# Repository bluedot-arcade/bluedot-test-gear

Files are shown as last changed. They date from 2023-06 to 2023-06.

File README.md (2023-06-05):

<p align="right">
    
     
</p>
<br><br>
<p align="center">
    <h1 align="center">BlueDot Test Gear</h1>
    <p align="center">This repository contains the source code and the design files for the bluedot automated test gear.</p>
    <p align="center"><strong><a href="https://docs.bluedotarcade.com/boards/bd845-pwb">Explore the docs</a></strong></p>
    <br><br>
</p>

## Testers

- [BD845-PWB Tester](/bd845-pwb-tester/)

## License

Distributed under the MIT License. See [LICENSE.txt] for more information.

<p align="right">(<a href="#readme-top">back to top</a>)</p>

[LICENSE.txt]: /LICENSE.txt
[PlatformIO Core Docs]: https://docs.platformio.org/en/latest/core/index.html
[PlatformIO Docs]: https://docs.platformio.org/

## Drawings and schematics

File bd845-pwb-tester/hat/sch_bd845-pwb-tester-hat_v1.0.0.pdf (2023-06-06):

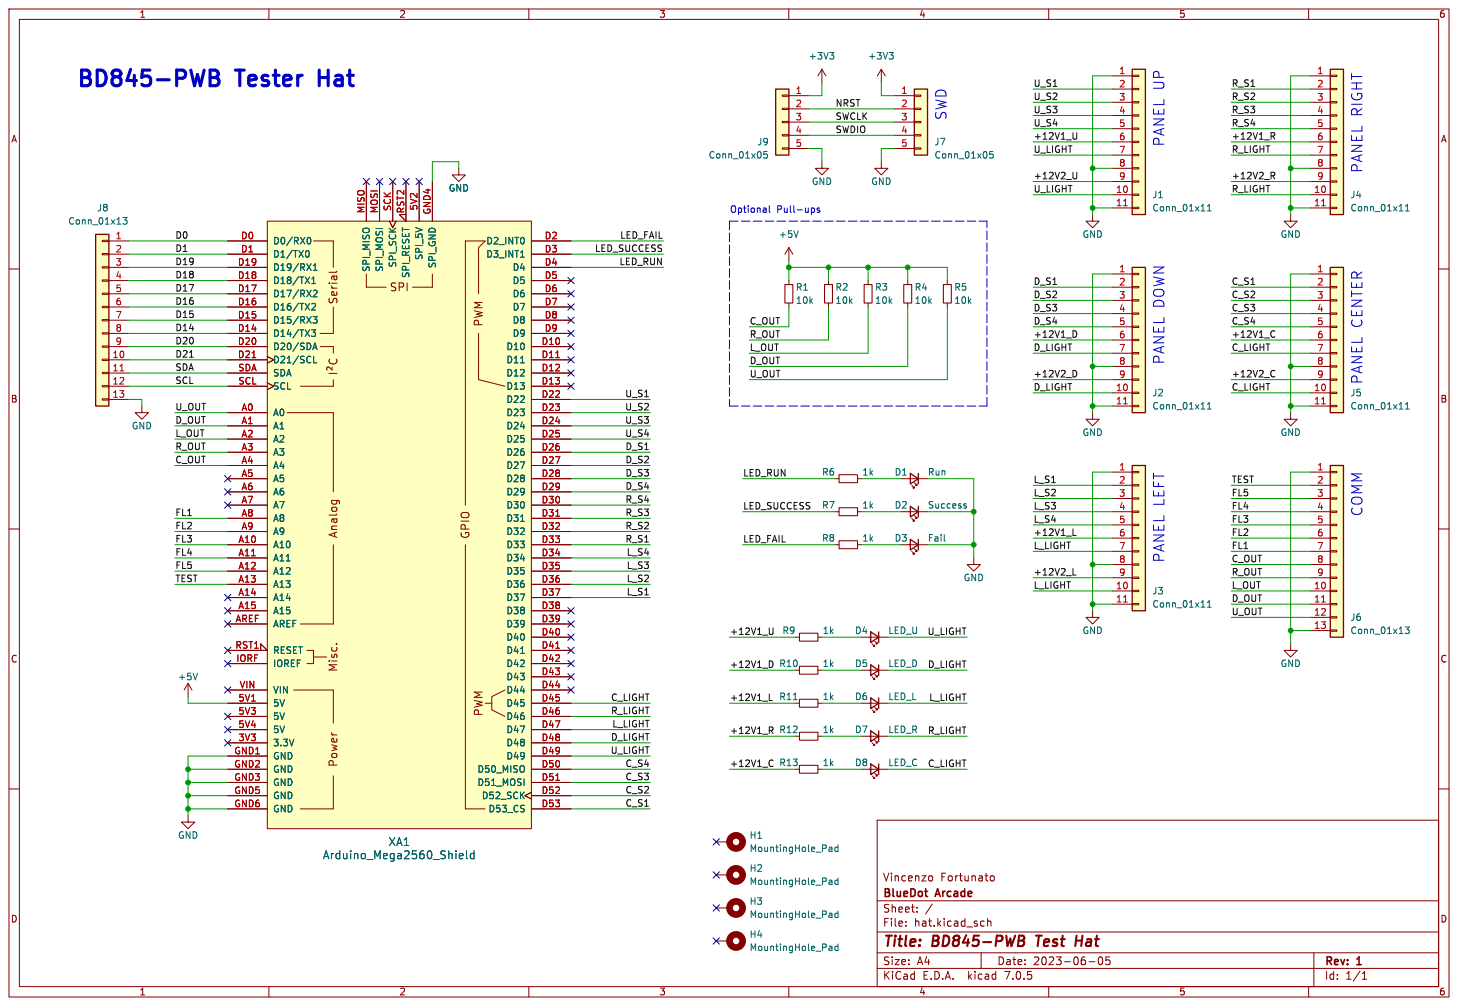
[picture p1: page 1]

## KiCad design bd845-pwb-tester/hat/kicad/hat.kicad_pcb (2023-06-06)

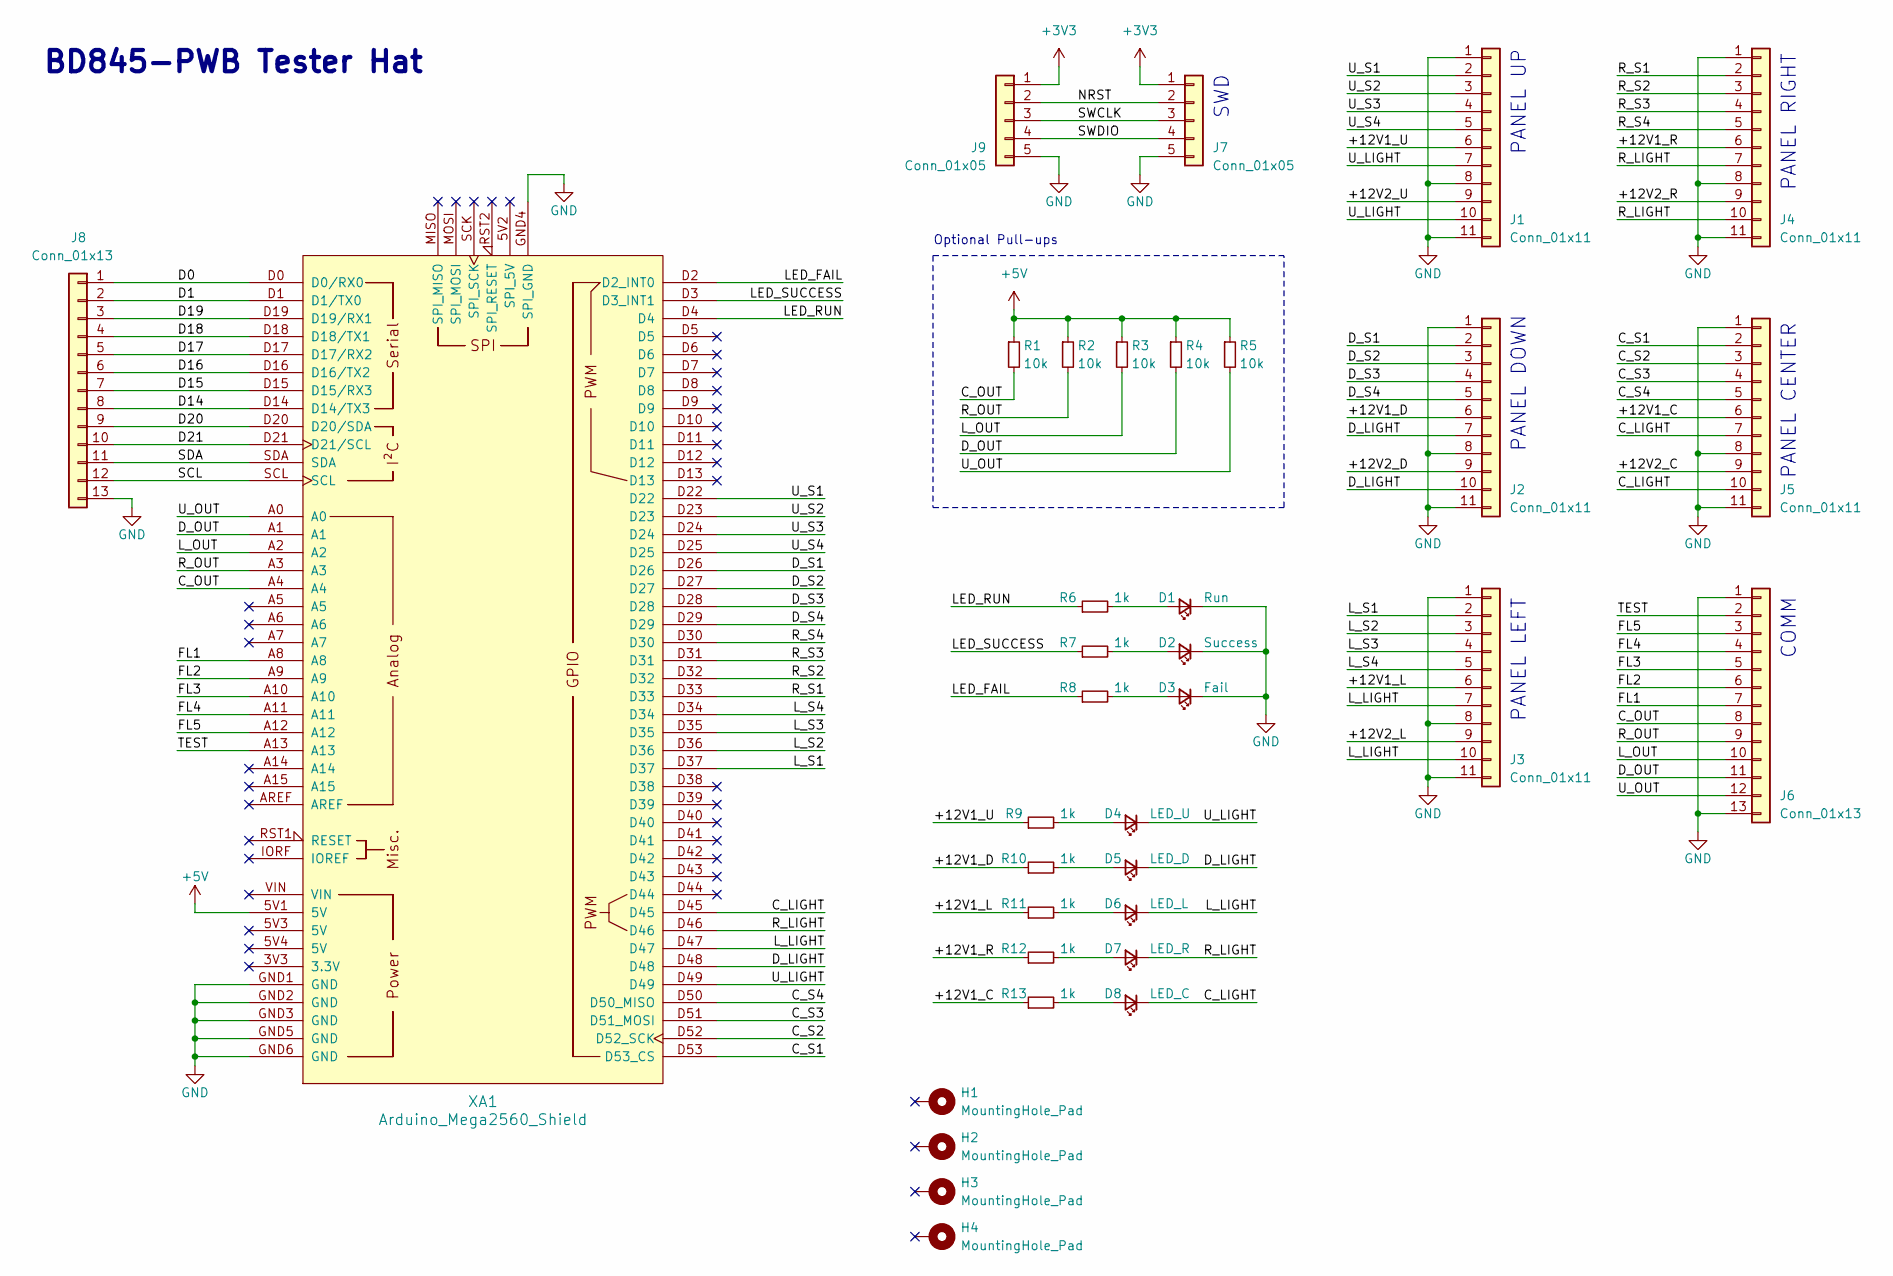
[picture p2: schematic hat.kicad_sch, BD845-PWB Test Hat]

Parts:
D1: Run; LED_D3.0mm
D2: Success; LED_D3.0mm
D3: Fail; LED_D3.0mm
D4: LED_U; LED_D3.0mm
D5: LED_D; LED_D3.0mm
D6: LED_L; LED_D3.0mm
D7: LED_R; LED_D3.0mm
D8: LED_C; LED_D3.0mm
H1, H2, H3, H4: MountingHole_Pad; MountingHole_4mm
J1, J2, J3, J4, J5: Conn_01x11; PinHeader_1x11_P2.54mm_Vertical
J6, J8: Conn_01x13; PinHeader_1x13_P2.54mm_Vertical
J7, J9: Conn_01x05; PinHeader_1x05_P2.54mm_Vertical
R1, R2, R3, R4, R5: 10k; R_Axial_DIN0207_L6.3mm_D2.5mm_P10.16mm_Horizontal
R6, R7, R8, R9, R10, R11, R12, R13: 1k; R_Axial_DIN0207_L6.3mm_D2.5mm_P10.16mm_Horizontal
XA1: Arduino_Mega2560_Shield

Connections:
+3V3: J7.1, J9.1
+5V: R1.1, R2.1, R3.1, R4.1, R5.1, XA1.5V1 (5V)
/+12V1_C: J5.6, R13.1
/+12V1_D: J2.6, R10.1
/+12V1_L: J3.6, R11.1
/+12V1_R: J4.6, R12.1
/+12V1_U: J1.6, R9.1
/+12V2_C: J5.9
/+12V2_D: J2.9
/+12V2_L: J3.9
/+12V2_R: J4.9
/+12V2_U: J1.9
/C_LIGHT: D8.1 (K), J5.7, J5.10, XA1.D45
/C_OUT: J6.8, R1.2, XA1.A4
/C_S1: J5.2, XA1.D53 (D53_CS)
/C_S2: J5.3, XA1.D52 (D52_SCK)
/C_S3: J5.4, XA1.D51 (D51_MOSI)
/C_S4: J5.5, XA1.D50 (D50_MISO)
/D0: J8.1, XA1.D0 (D0/RX0)
/D1: J8.2, XA1.D1 (D1/TX0)
/D14: J8.8, XA1.D14 (D14/TX3)
/D15: J8.7, XA1.D15 (D15/RX3)
/D16: J8.6, XA1.D16 (D16/TX2)
/D17: J8.5, XA1.D17 (D17/RX2)
/D18: J8.4, XA1.D18 (D18/TX1)
/D19: J8.3, XA1.D19 (D19/RX1)
/D20: J8.9, XA1.D20 (D20/SDA)
/D21: J8.10, XA1.D21 (D21/SCL)
/D_LIGHT: D5.1 (K), J2.7, J2.10, XA1.D48
/D_OUT: J6.11, R4.2, XA1.A1
/D_S1: J2.2, XA1.D26
/D_S2: J2.3, XA1.D27
/D_S3: J2.4, XA1.D28
/D_S4: J2.5, XA1.D29
/FL1: J6.7, XA1.A8
/FL2: J6.6, XA1.A9
/FL3: J6.5, XA1.A10
/FL4: J6.4, XA1.A11
/FL5: J6.3, XA1.A12
/LED_FAIL: R8.1, XA1.D2 (D2_INT0)
/LED_RUN: R6.1, XA1.D4
/LED_SUCCESS: R7.1, XA1.D3 (D3_INT1)
/L_LIGHT: D6.1 (K), J3.7, J3.10, XA1.D47
/L_OUT: J6.10, R3.2, XA1.A2
/L_S1: J3.2, XA1.D37
/L_S2: J3.3, XA1.D36
/L_S3: J3.4, XA1.D35
/L_S4: J3.5, XA1.D34
/NRST: J7.2, J9.2
/R_LIGHT: D7.1 (K), J4.7, J4.10, XA1.D46
/R_OUT: J6.9, R2.2, XA1.A3
/R_S1: J4.2, XA1.D33
/R_S2: J4.3, XA1.D32
/R_S3: J4.4, XA1.D31
/R_S4: J4.5, XA1.D30
/SCL: J8.12, XA1.SCL
/SDA: J8.11, XA1.SDA
/SWCLK: J7.3, J9.3
/SWDIO: J7.4, J9.4
/TEST: J6.2, XA1.A13
/U_LIGHT: D4.1 (K), J1.7, J1.10, XA1.D49
/U_OUT: J6.12, R5.2, XA1.A0
/U_S1: J1.2, XA1.D22
/U_S2: J1.3, XA1.D23
/U_S3: J1.4, XA1.D24
/U_S4: J1.5, XA1.D25
GND: D1.1 (K), D2.1 (K), D3.1 (K), J1.1, J1.8, J1.11, J2.1, J2.8, J2.11, J3.1, J3.8, J3.11, J4.1, J4.8, J4.11, J5.1, J5.8, J5.11, J6.1, J6.13, J7.5, J8.13, J9.5, XA1.GND1 (GND), XA1.GND2 (GND), XA1.GND3 (GND), XA1.GND4 (SPI_GND), XA1.GND5 (GND), XA1.GND6 (GND)
unnamed: D1.2 (A), R6.2
unnamed: D2.2 (A), R7.2
unnamed: D3.2 (A), R8.2
unnamed: D4.2 (A), R9.2
unnamed: D5.2 (A), R10.2
unnamed: D6.2 (A), R11.2
unnamed: D7.2 (A), R12.2
unnamed: D8.2 (A), R13.2

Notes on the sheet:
BD845-PWB Tester Hat
Optional Pull-ups
COMM
SWD
PANEL LEFT
PANEL CENTER
PANEL UP
PANEL RIGHT
PANEL DOWN

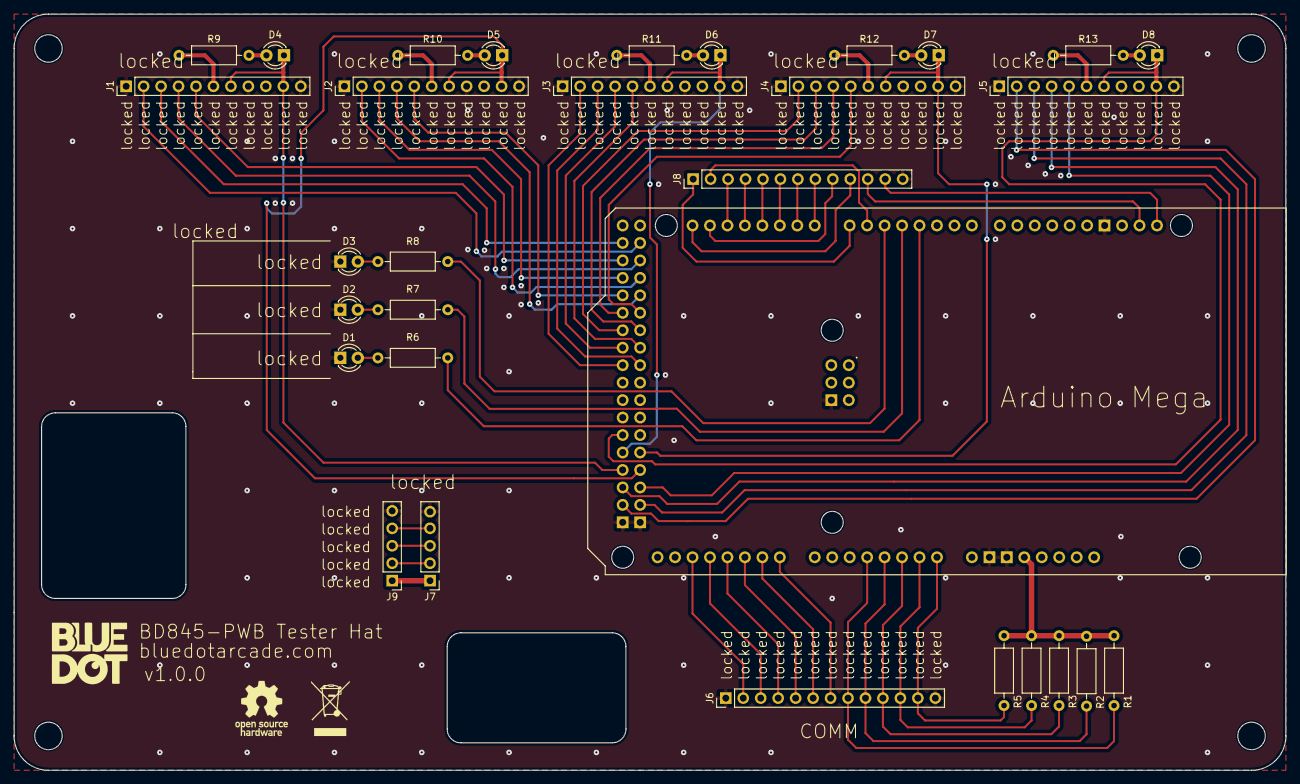
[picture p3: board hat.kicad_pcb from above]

Board: 2 copper layers, 185.0 x 110.0 mm, 35 parts (1 on the bottom side), 70 nets.

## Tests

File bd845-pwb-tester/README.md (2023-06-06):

<p align="right">
    
      
</p>
<br><br>
<p align="center">
    <h1 align="center">BD845-PWB Tester</h1>
    <p align="center">This repository contains the source code and the design files of the BD845-PWB Tester.</p>
    <p align="center"><strong><a href="https://github.com/bluedot-arcade/bd845-pwb-board">Go to board repository</a></strong></p>
    <p align="center"><strong><a href="https://docs.bluedotarcade.com/boards/bd845-pwb">Explore the docs</a></strong></p>
    <br><br>
</p>

## About the project

The BD845-PWB Tester is a test gear specifically designed to automate the [BD845-PWB] board physical tests. 

It is based on an Arduino Mega (or any compatible board). An additional hat is provided to avoid a flying wires setup and speed up the testing procedure.

<p align="right">(<a href="#readme-top">back to top</a>)</p>

## Test procedure

This section describes the steps required to perform the tests.

### 1. Build and upload test program to the Arduino Mega

This project uses PlatformIO to build and upload the project. Only the PlatformIO Core CLI is required but consider installing the PlatformIO IDE for a better user experience.

The following is the recommended way to build and upload the firmware.

1. [Install PlatformIO Core.][PlatformIO Core Docs]

2. Clone the repository.
    ```bash
    git clone https://github.com/bluedot-arcade/bluedot-test-gear
    ```

3. Navigate to the root of the project.
   ```bash
    cd bluedot-test-gear/bd845-pwb-tester
    ```

4. Build the project. Binaries will be created inside the `.pio` folder.
    ```bash
    platformio run
    ```
    
5. Upload the project to the Arduino Mega.
    ```bash
    platformio run --target upload
    ```

If you prefer using the Arduino IDE the full code is contained in `src/main.cpp`. Just rename it to `main.ino`.

<p align="right">(<a href="#readme-top">back to top</a>)</p>

### 2. Set up test gear

Wire the Arduino Mega to the BD845-PWB. This does not require any additional components other than wires for direct connection of the pins.

Alternatively you can use the provided hat.

The following is the Arduino Mega <-> BD845-PWB pins mapping table.

| Arduino Mega Pin | BD845-PWB Pin | | Arduino Mega Pin | BD845-PWB Pin |
| --- | --- |-| --- | --- |
| A0 | U_OUT |-| D37 | L_S1 |
| A1 | D_OUT |-| D36 | L_S2 |
| A2 | L_OUT |-| D35 | L_S3 |
| A3 | R_OUT |-| D34 | L_S4 |
| A4 | C_OUT |-| D33 | R_S1 |
| A8 | FL1 |-| D32 | R_S2 |
| A9 | FL2 |-| D31 | R_S3 |
| A10 | FL3 |-| D30 | R_S4 |
| A11 | FL4 |-| D53 | C_S1 |
| A12 | FL5 |-| D52 | C_S2 |
| A13 | TEST |-| D51 | C_S3 |
| D22 | U_S1 |-| D50 | C_S4 |
| D23 | U_S2 |-| D49 | U_LIGHT |
| D24 | U_S3 |-| D48 | D_LIGHT |
| D25 | U_S4 |-| D47 | L_LIGHT |
| D26 | D_S1 |-| D46 | R_LIGHT |
| D27 | D_S2 |-| D45 | C_LIGHT |
| D28 | D_S3 |-|
| D29 | D_S4 |-|

The full pinout for the BD845-PWB can be found in the [docs][BD845-PWB Docs].

<p align="right">(<a href="#readme-top">back to top</a>)</p>

### 3. Run test routines

Test routines can be run using a serial monitor from a computer.

1. Connect the Arduino Mega to a computer with a USB cable.
2. Connect the BD845-PWB power connector to a +12V supply.
3. On the computer open the serial monitor, open the Arduino Mega serial port and set the baud rate to 115200. A menu with all test routines will be printed.
   
    ```bash
    *** BD845-PWB Test Routines ***

    Select option:
    1. Test inputs
    2. Test lights external
    3. Test lights press mode
    4. Test debounce
    5. Test legacy
    ```
4. Select the routine to run by writing the corresponding number to the serial monitor.
5. "TEST SUCCESSFUL" will be printed on success. Otherwise "TEST FAILED" will be printed and the built-in LED on Arduino Mega will light up.

<p align="right">(<a href="#readme-top">back to top</a>)</p>

## Hat board

The [/hat](hat/) folder contains the project files for an hat board that simplifies the connection between the Arduino Mega and the BD845-PWB board, speeding up testing without the use of stray wires.

It also comes with additional LED indicators for test status and light driver tests.

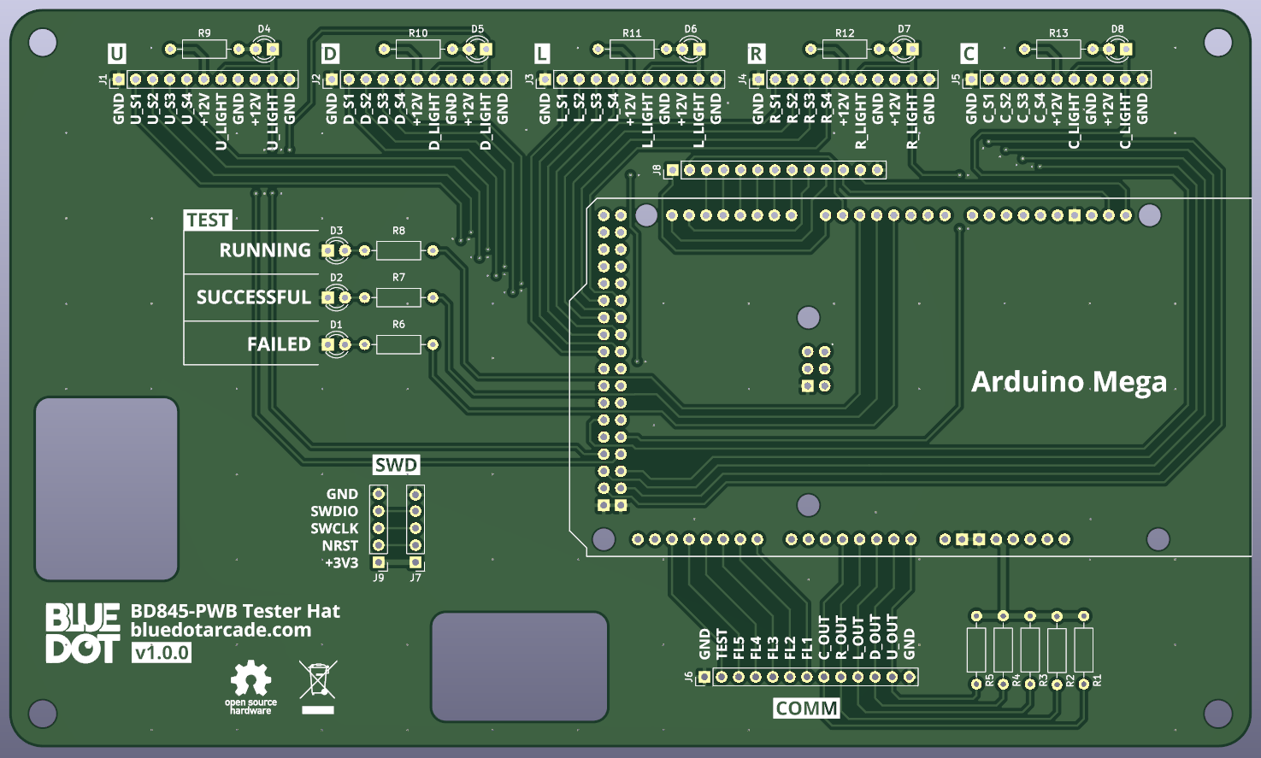
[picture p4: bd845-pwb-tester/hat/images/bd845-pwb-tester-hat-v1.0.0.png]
BD845-PWB-Tester-Hat


## License

Distributed under the MIT License. See [LICENSE.txt] for more information.

<p align="right">(<a href="#readme-top">back to top</a>)</p>

[LICENSE.txt]: /LICENSE.txt
[PlatformIO Core Docs]: https://dohttps://docs.bluedotarcade.com/boards/bd845-pwbcs.platformio.org/en/latest/core/index.html
[PlatformIO Docs]: https://docs.platformio.org/
[BD845-PWB]: https://github.com/bluedot-arcade/bd845-pwb-board
[BD845-PWB Docs]: https://docs.bluedotarcade.com/boards/bd845-pwb

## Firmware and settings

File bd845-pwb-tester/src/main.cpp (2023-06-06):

#include <Arduino.h>

/* Compile options */
// #define USE_EXTERNAL_PULLUPS

/* Commands */

#define CMD_TEST_INPUTS '1'
#define CMD_TEST_LIGHTS_EXT '2'
#define CMD_TEST_LIGHTS_PRESS '3'
#define CMD_TEST_DEBOUNCE '4'
#define CMD_TEST_LEGACY '5'

/* States */
#define STATE_IDLE 0
#define STATE_TEST_RUNNING 1
#define STATE_TEST_FAILED 2
#define STATE_TEST_SUCCESSFUL 3

/* 
 * Map Arduino Mega pins to BD845-PWB pins.
 * The pinout for the BD845-PWB can be found here 
 * https://docs.bluedotarcade.com/boards/bd845-pwb
 */

/* Comm inputs */

#define FL1       PK0
#define FL2       PK1
#define FL3       PK2
#define FL4       PK3
#define FL5       PK4
#define TEST      PK5
#define IN_DDR    DDRK
#define IN_PORT   PORTK
#define IN_OFFSET 0

/* Comm outputs */

#define U_OUT      PF0 
#define D_OUT      PF1 
#define L_OUT      PF2 
#define R_OUT      PF3 
#define C_OUT      PF4 
#define OUT_DDR    DDRF
#define OUT_PIN    PINF
#define OUT_OFFSET 0

/* Panel up sensors */

#define U_S1     PA0 
#define U_S2     PA1 
#define U_S3     PA2 
#define U_S4     PA3 
#define U_DDR    DDRA
#define U_PORT   PORTA
#define U_OFFSET 0

/* Panel down sensors */

#define D_S1     PA4 
#define D_S2     PA5 
#define D_S3     PA6 
#define D_S4     PA7 
#define D_DDR    DDRA
#define D_PORT   PORTA
#define D_OFFSET 4

/* Panel left sensors */

#define L_S1     PC0 
#define L_S2     PC1 
#define L_S3     PC2 
#define L_S4     PC3 
#define L_DDR    DDRC
#define L_PORT   PORTC
#define L_OFFSET 0

/* Panel right sensors */

#define R_S1     PC4 
#define R_S2     PC5 
#define R_S3     PC6 
#define R_S4     PC7 
#define R_DDR    DDRC
#define R_PORT   PORTC3
#define R_OFFSET 4

/* Panel center sensors */

#define C_S1     PB0 
#define C_S2     PB1 
#define C_S3     PB2 
#define C_S4     PB3 
#define C_DDR    DDRB
#define C_PORT   PORTB
#define C_OFFSET 0

/* Lights */

#define U_LIGHT      PL0 
#define D_LIGHT      PL1 
#define L_LIGHT      PL2 
#define R_LIGHT      PL3 
#define C_LIGHT      PL4
#define LIGHT_DDR    DDRL
#define LIGHT_PIN    PINL
#define LIGHT_OFFSET 0

/* Hat pins */

#define LED_FAIL    PE4
#define LED_SUCCESS PE5
#define LED_RUN     PE6 

void setupSerialPort();
void setupLeds();
void setupCommInputPins();
void setupCommOutputPins();
void setupUpPins();
void setupDownPins();
void setupLeftPins();
void setupRightPins();
void setupCenterPins();
void setupLightPins();

bool testInputs();
bool testLightsExt();
bool testLightsPress();
bool testDebounce();
bool testLegacy();

uint8_t readCommOutputPins();
uint8_t readLightPins();
void setCommInputPins(uint8_t state);
void setUpPins(uint8_t state);
void setDownPins(uint8_t state);
void setLeftPins(uint8_t state);
void setRightPins(uint8_t state);
void setCenterPins(uint8_t state);
void setHighZ(int pin);
void printMenu();
void setState(uint8_t state);

// Setup ---------------------------------------------------------------

void setup() {
  setupSerialPort();
  setupLeds();

  setupCommInputPins();
  setupCommOutputPins();
  
  setupUpPins();
  setupDownPins();
  setupLeftPins();
  setupRightPins();
  setupLightPins();
}

void setupSerialPort() {
  Serial.begin(115200);
}

void setupLeds() {
  pinMode(LED_BUILTIN, OUTPUT);
  digitalWrite(LED_BUILTIN, LOW);
  
  pinMode(LED_FAIL, OUTPUT);
  digitalWrite(LED_FAIL, LOW);

  pinMode(LED_SUCCESS, OUTPUT);
  digitalWrite(LED_SUCCESS, LOW);

  pinMode(LED_RUN, OUTPUT);
  digitalWrite(LED_RUN, LOW);
}

void setupCommInputPins() {
  setHighZ(TEST);
  setHighZ(FL5);
  setHighZ(FL4);
  setHighZ(FL3);
  setHighZ(FL2);
  setHighZ(FL1);
}

void setupCommOutputPins() {
  #ifdef USE_EXTERNAL_PULLUPS
  pinMode(C_OUT, INPUT);
  pinMode(R_OUT, INPUT);
  pinMode(L_OUT, INPUT);
  pinMode(D_OUT, INPUT);
  pinMode(U_OUT, INPUT);
  #else
  pinMode(C_OUT, INPUT_PULLUP);
  pinMode(R_OUT, INPUT_PULLUP);
  pinMode(L_OUT, INPUT_PULLUP);
  pinMode(D_OUT, INPUT_PULLUP);
  pinMode(U_OUT, INPUT_PULLUP);
  #endif
}

void setupUpPins() {
  setHighZ(U_S1);pinMode(LED_FAIL, OUTPUT);
  digitalWrite(LED_FAIL, LOW);
  setHighZ(U_S2);
  setHighZ(U_S3);
  setHighZ(U_S4);
}

void setupDownPins() {
  setHighZ(U_S1);
  setHighZ(U_S2);
  setHighZ(U_S3);
  setHighZ(U_S4);
}

void setupLeftPins() {
  setHighZ(U_S1);
  setHighZ(U_S2);
  setHighZ(U_S3);
  setHighZ(U_S4);
}

void setupRightPins() {
  setHighZ(U_S1);
  setHighZ(U_S2);
  setHighZ(U_S3);
  setHighZ(U_S4);
}

void setupCenterPins() {
  setHighZ(U_S1);
  setHighZ(U_S2);
  setHighZ(U_S3);
  setHighZ(U_S4);
}

void setupLightPins() {
  pinMode(U_LIGHT, INPUT_PULLUP);
  pinMode(D_LIGHT, INPUT_PULLUP);
  pinMode(L_LIGHT, INPUT_PULLUP);
  pinMode(R_LIGHT, INPUT_PULLUP);
  pinMode(C_LIGHT, INPUT_PULLUP);
}

// Loop ----------------------------------------------------------------

void loop() {
  //Serial.flush();
  printMenu();

  // Wait for command
  while(Serial.available() <= 0);

  setState(STATE_IDLE);
  char cmd = Serial.read();
  bool successful = true;
 
  switch(cmd) {
    case CMD_TEST_INPUTS:
      setState(STATE_TEST_RUNNING);
      successful = testInputs();
      break;
    case CMD_TEST_LIGHTS_EXT:
      setState(STATE_TEST_RUNNING);
      successful = testLightsExt();
      break;
    case CMD_TEST_LIGHTS_PRESS:
      setState(STATE_TEST_RUNNING);
      successful = testLightsPress();
      break;
    case CMD_TEST_DEBOUNCE:
      setState(STATE_TEST_RUNNING);
      successful = testDebounce();
      break;
    case CMD_TEST_LEGACY:
      setState(STATE_TEST_RUNNING);
      successful = testLegacy();
      break;
    default:
      Serial.println(F("Command not found!"));
      return;
  }

  if(successful) {
    setState(STATE_TEST_SUCCESSFUL);
    Serial.println(F("TEST SUCCESSFUL"));
  } else {
    setState(STATE_TEST_FAILED);
    Serial.println(F("TEST FAILED"));
  }
}

bool testInputs() {
  uint8_t up = 0;
  uint8_t down = 0;
  uint8_t left = 0;
  uint8_t right = 0;
  uint8_t center = 0;

  setUpPins(up);
  setDownPins(down);
  setLeftPins(left);
  setRightPins(right);
  setCenterPins(center);

  if(readCommOutputPins() != 0)
    return false;
  
  while(++up < 0x10) {
    setUpPins(up);

    if(readCommOutputPins() != U_OUT)
      return false;
  }

  return true;
}

bool testLightsExt() {
  Serial.println(F("Testing lights external..."));
  uint8_t inputs = 0;
  uint8_t lights = 0;
  uint8_t expected = 0;

  while(inputs < 0x20) {
    setCommInputPins(inputs);
    delay(1);
    lights = readLightPins();
    expected = ~inputs & 0x1F;
    
    if(lights != expected) {
      Serial.print(F("inputs: "));
      Serial.print(inputs, HEX);
      Serial.print(F(", lights: "));
      Serial.print(lights, HEX);
      Serial.print(F(", expected: "));
      Serial.print(expected, HEX);
      Serial.println();
      return false;
    }
    
    inputs++;
  }

  return true;
}

bool testLightsPress() {
  return true;
}

bool testDebounce() {
  return true;
}

bool testLegacy() {

  return true;
}

// Utilities -----------------------------------------------------------

uint8_t readCommOutputPins() {
  return OUT_PIN & (0x1F << OUT_OFFSET);
}

uint8_t readLightPins() {
  return LIGHT_PIN & (0x1F << LIGHT_OFFSET);
}

void setCommInputPins(uint8_t state) {
  IN_DDR = (IN_DDR & (0xC0 >> IN_OFFSET)) | (state << IN_OFFSET);
}

void setUpPins(uint8_t state) {
  U_DDR = (U_DDR & (0xF0 >> U_OFFSET)) | (state << U_OFFSET);
}

void setDownPins(uint8_t state) {
  D_DDR = (D_DDR & (0xF0 >> D_OFFSET)) | (state << D_OFFSET);
}

void setLeftPins(uint8_t state) {
  L_DDR = (L_DDR & (0xF0 >> L_OFFSET)) | (state << L_OFFSET);
}

void setRightPins(uint8_t state) {
  R_DDR = (R_DDR & (0xF0 >> R_OFFSET)) | (state << R_OFFSET);
}

void setCenterPins(uint8_t state) {
  C_DDR = (C_DDR & (0xF0 >> C_OFFSET)) | (state << C_OFFSET);
}

void setHighZ(int pin) {
  digitalWrite(pin, LOW);
  pinMode(pin, INPUT);
}

void printMenu() {
  Serial.println(F("\n*** BD845-PWB Test Routines ***\n"));
  Serial.println(F("Select option:"));
  Serial.println(F("1. Test inputs"));
  Serial.println(F("2. Test lights external"));
  Serial.println(F("3. Test lights press mode"));
  Serial.println(F("4. Test debounce"));
  Serial.println(F("5. Test legacy"));
  Serial.println();
}

void setState(uint8_t state) {
  switch(state) {
    case STATE_IDLE:
      digitalWrite(LED_BUILTIN, LOW);
      digitalWrite(LED_FAIL, LOW);
      digitalWrite(LED_SUCCESS, LOW);
      digitalWrite(LED_RUN, LOW);
      break;
    case STATE_TEST_RUNNING:
      digitalWrite(LED_BUILTIN, LOW);
      digitalWrite(LED_FAIL, LOW);
      digitalWrite(LED_SUCCESS, LOW);
      digitalWrite(LED_RUN, HIGH);
      break;
    case STATE_TEST_FAILED:
      digitalWrite(LED_BUILTIN, HIGH);
      digitalWrite(LED_FAIL, HIGH);
      digitalWrite(LED_SUCCESS, LOW);
      digitalWrite(LED_RUN, LOW);
      break;
    case STATE_TEST_SUCCESSFUL:
      digitalWrite(LED_BUILTIN, LOW);
      digitalWrite(LED_FAIL, LOW);
      digitalWrite(LED_SUCCESS, HIGH);
      digitalWrite(LED_RUN, LOW);
      break;
  }
}

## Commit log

2023-06-05 Import hat project.
    [hat.kicad_pcb, hat.kicad_sch]
2023-06-06 Hat board v1.0.0.
    [hat-B_Cu.gbr, hat-B_Mask.gbr, hat-B_Paste.gbr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]
2023-06-06 Fix wrong pin defines.
    [main.cpp]
2023-06-06 Update pin defines. Add state management function. Add external pullup compilation option.

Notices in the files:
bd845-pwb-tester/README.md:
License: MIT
